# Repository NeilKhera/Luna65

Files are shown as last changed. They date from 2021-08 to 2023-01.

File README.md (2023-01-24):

## Luna65
Luna65 is my first PCB project - a 65% keyboard!

### Disclaimer
This is very much a WIP project which means there will be issues and incomplete features - especially on the software side. This is my first hardware project
and I do not claim to be an expert in the field. While physical versions of the PCB have been tested and are known to work, I do not promise that my implementation
is perfect. For example, the Atmega32u4 microprocessor used in this project does not have sufficient GPIO to enable a clean 5 row x 15 column matrix standard for 65%
keyboards. As such the keys are laid out in an unconventional (and definitely ugly) 6x12 matrix. I do not intend to improve or fix this.

TL;DR This project is provided as is. You are free to use it however you like but I have no intention to polish it into a complete ready-to-ship product. Functionality
may be added or removed at any moment and the project will be abandoned whenever I get too bored to carry on.
(Do, let me know if you actually get some boards made - that'd be sickkkkk!)

### License
Designed by Neil Khera.

Creative Commons Attribution/Share-Alike. See license.txt for additional details.

__

_fin._

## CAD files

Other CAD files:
resources/Draw1.DXF
resources/Luna65-Case-Bottom.DXF
resources/Luna65-Case-Top.DXF
resources/Luna65-Plate (Gasket).DXF
resources/Luna65-Case.DXF
resources/Luna65-Plate.DXF
resources/Draw1.SLDDRW

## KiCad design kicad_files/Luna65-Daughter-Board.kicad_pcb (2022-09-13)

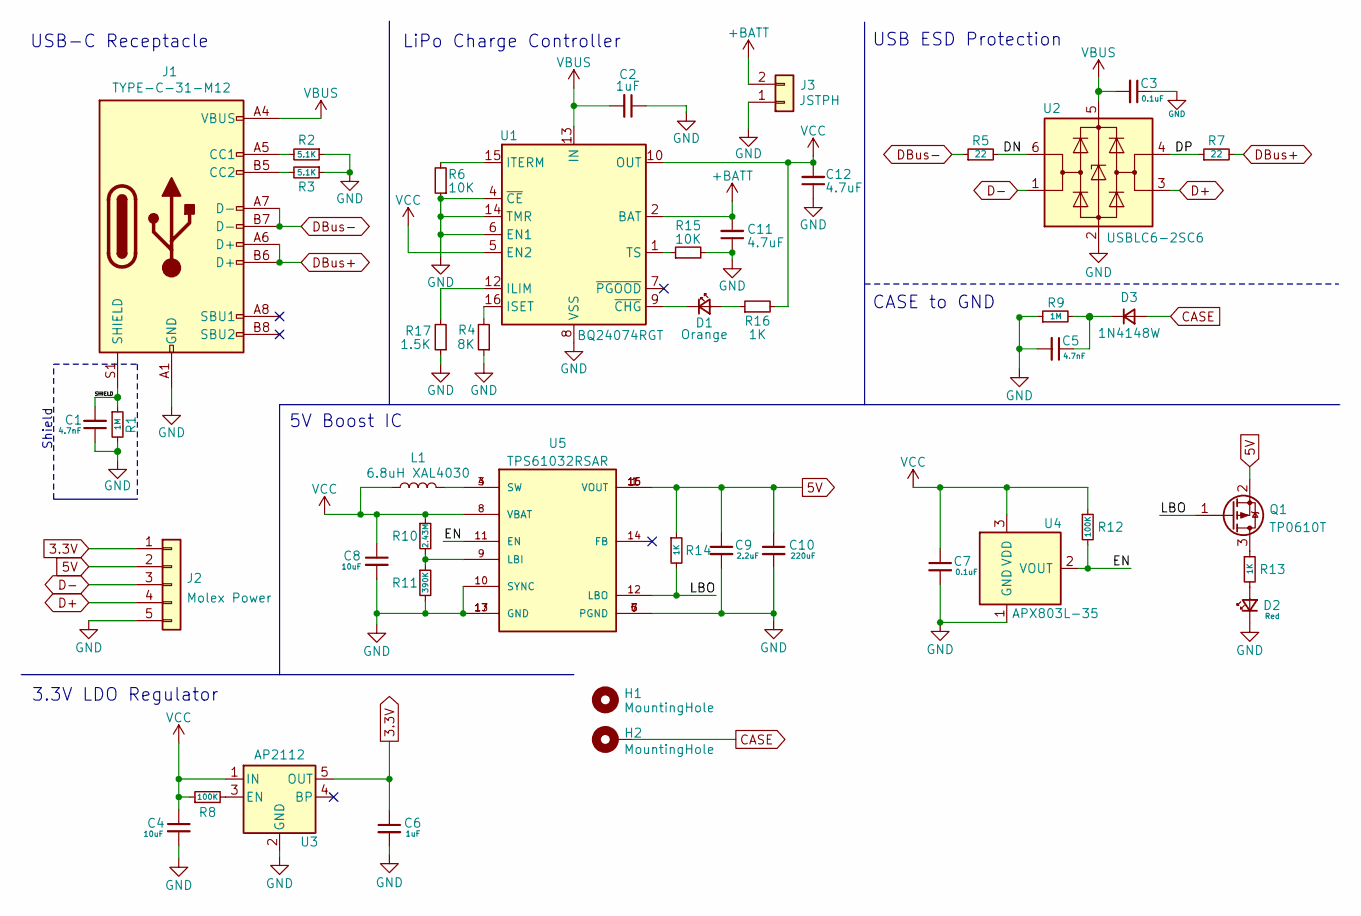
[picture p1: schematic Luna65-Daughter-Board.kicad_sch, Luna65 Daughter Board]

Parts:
C1, C5: 4.7nF; C_0603_1608Metric
C2, C6: 1uF; C_0603_1608Metric
C3, C7: 0.1uF; C_0603_1608Metric
C4, C8: 10uF; C_0603_1608Metric
C9: 2.2uF; C_0603_1608Metric
C10: 220uF; C_1206_3216Metric
C11, C12: 4.7uF; C_0603_1608Metric
D1: Orange; LED_0805_2012Metric
D2: Red; LED_0805_2012Metric
D3: 1N4148W; D_SOD-123
H1: MountingHole; MountingHole_2.2mm_M2
H2: MountingHole; MountingHole_2.2mm_M2_Pad
J1: TYPE-C-31-M12; USB_C_Receptacle_Hroparts_TYPE-C-31-M-12
J2: Molex Power; MOLEX_78171-0005
J3: JSTPH; JSTPH2
L1: 6.8uH XAL4030; XAL4030
Q1: TP0610T; SOT-23
R1, R9: 1M; R_0603_1608Metric
R2, R3: 5.1K; R_0603_1608Metric
R4: 8K; R_0603_1608Metric
R5, R7: 22; R_0603_1608Metric
R6, R15: 10K; R_0603_1608Metric
R8, R12: 100K; R_0603_1608Metric
R10: 2.43M; R_0603_1608Metric
R11: 390K; R_0603_1608Metric
R13, R14, R16: 1K; R_0603_1608Metric
R17: 1.5K; R_0603_1608Metric
U1: BQ24074RGT; VQFN-16-1EP_3x3mm_P0.5mm_EP1.6x1.6mm
U2: USBLC6-2SC6; SOT-23-6
U3: AP2112; SOT-23-5
U4: APX803L-35; SOT-23
U5: TPS61032RSAR; Texas_S-PVQFN-N16_EP2.7x2.7mm

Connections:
3.3V: C6.1, J2.1, U3.5 (OUT)
5V: C9.1, C10.1, J2.2, Q1.2 (S), R14.1, U5.1 (VOUT), U5.15 (VOUT), U5.16 (VOUT)
+BATT: C11.2, J3.2, U1.2 (BAT), U1.3 (BAT)
/DN: R5.2, U2.6 (I/O1)
/DP: R7.1, U2.4 (I/O2)
/EN: R12.2, U4.2 (VOUT), U5.11 (EN)
/LBO: Q1.1 (G), R14.2, U5.12 (LBO)
/SHIELD: C1.2, J1.S1 (SHIELD), R1.1
CASE: D3.2 (A), H2.1
D+: J2.4, U2.3 (I/O2)
D-: J2.3, U2.1 (I/O1)
DBus+: J1.A6 (D+), J1.B6 (D+), R7.2
DBus-: J1.A7 (D-), J1.B7 (D-), R5.1
GND: C1.1, C2.1, C3.1, C4.2, C5.2, C6.2, C7.2, C8.2, C9.2, C10.2, C11.1, C12.1, D2.1 (K), J1.A1 (GND), J1.B1 (GND), J2.5, J3.1, R1.2, R2.1, R3.1, R4.1, R6.1, R9.1, R11.2, R15.2, R17.1, U1.4 (~CE), U1.6 (EN1), U1.8 (VSS), U1.14 (TMR), U1.17 (VSS), U2.2 (GND), U3.2 (GND), U4.1 (GND), U5.5 (PGND), U5.6 (PGND), U5.7 (PGND), U5.10 (SYNC), U5.13 (GND), U5.17 (GND)
unnamed: C5.1, D3.1 (K), R9.2
unnamed: D1.1 (K), U1.9 (~CHG)
unnamed: D1.2 (A), R16.1
unnamed: D2.2 (A), R13.2
unnamed: J1.A5 (CC1), R2.2
unnamed: J1.B5 (CC2), R3.2
unnamed: L1.2, U5.3 (SW), U5.4 (SW)
unnamed: Q1.3 (D), R13.1
unnamed: R4.2, U1.16 (ISET)
unnamed: R6.2, U1.15 (ITERM)
unnamed: R8.2, U3.3 (EN)
unnamed: R10.2, R11.1, U5.9 (LBI)
unnamed: R15.1, U1.1 (TS)
unnamed: R17.2, U1.12 (ILIM)
VBUS: C2.2, C3.2, J1.A4 (VBUS), J1.B4 (VBUS), U1.13 (IN), U2.5 (VBUS)
VCC: C4.1, C7.1, C8.1, C12.2, L1.1, R8.1, R10.1, R12.1, R16.2, U1.5 (EN2), U1.10 (OUT), U1.11 (OUT), U3.1 (IN), U4.3 (VDD), U5.8 (VBAT)

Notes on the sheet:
3.3V LDO Regulator
5V Boost IC
CASE to GND
USB-C Receptacle
LiPo Charge Controller
Shield
USB ESD Protection

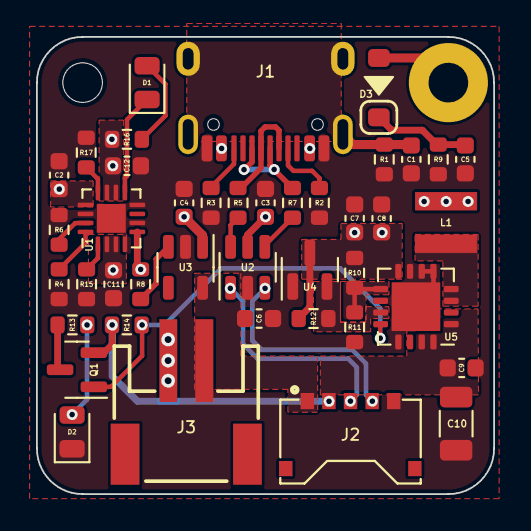
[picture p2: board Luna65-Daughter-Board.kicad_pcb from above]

Board: 2 copper layers, 25.4 x 25.4 mm, 44 parts (0 on the bottom side), 30 nets.

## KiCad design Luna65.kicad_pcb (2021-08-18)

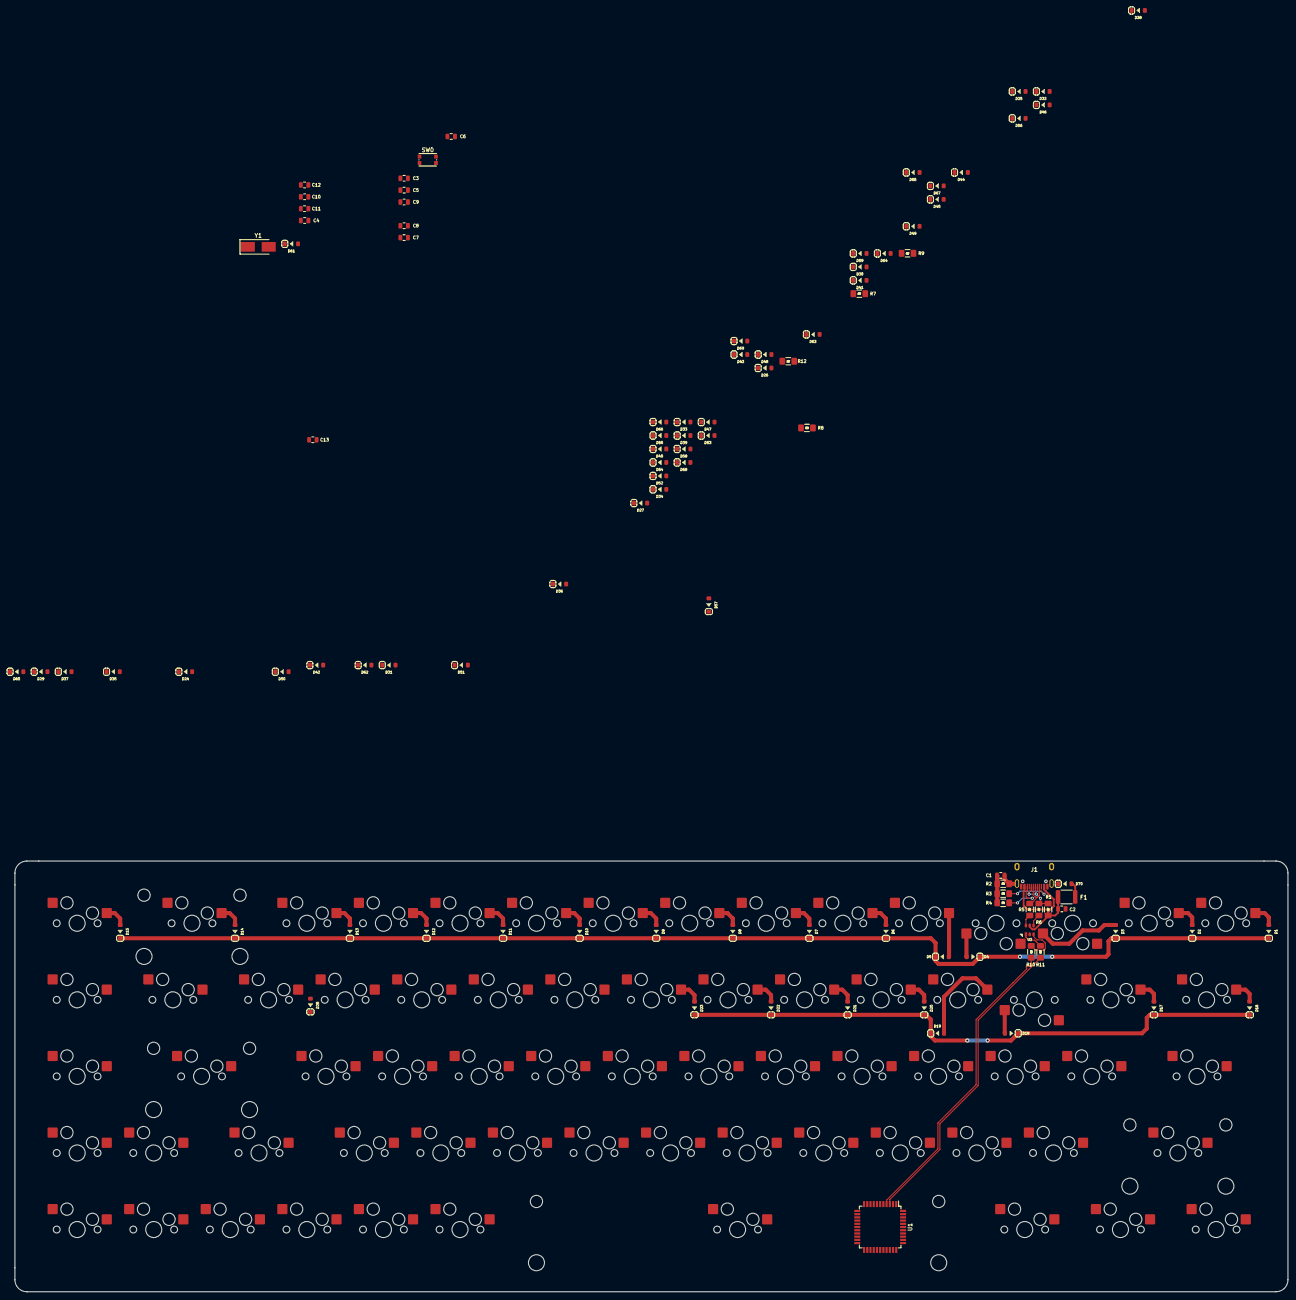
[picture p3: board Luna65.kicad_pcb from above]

Board: 2 copper layers, 316.7 x 107.2 mm, 169 parts (0 on the bottom side), 109 nets.

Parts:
C1, C13: 4.7nF; C_0805_2012Metric
C2: 100nF; C_0805_2012Metric
C3, C4, C8, C9: 0.1uF; C_0805_2012Metric
C5, C7, C12: 1uF; C_0805_2012Metric
C6: 10uF; C_0805_2012Metric
C10, C11: 22pF; C_0805_2012Metric
D1, D2, D3, D4, D5, D6, D7, D8, D9, D10, D11, D12, D13, D14, D15, D16, D17, D18, D19, D20, D21, D22, D23, D24, D25, D26, D27, D28, D29, D30, D31, D32, D33, D34, D35, D36, D37, D38, D39, D40, D41, D42, D43, D44, D45, D46, D47, D48, D49, D50, D51, D52, D53, D54, D55, D56, D57, D58, D59, D60, D61, D62, D63, D64, D65, D66, D67, D68: 1N4148W; D_SOD-123
D69: 1N4007; D_SOD-123
D70: RB060M-60TR; D_SOD-123
F1: Polyfuse_Small; Fuse_1812_4532
J1: TYPE-C-31-M12_13; TYPE-C-31-M-12
R1: 1.5K; R_SMD_1206
R2, R7: 1M; R_SMD_1206
R3, R4: 5.1k; R_SMD_1206
R5, R6, R10, R11: 22; R_SMD_1206
R8: 100; R_SMD_1206
R9: 10k; R_SMD_1206
R12: 1k; R_SMD_1206
SW0: SW_Push; SW_Push_1P1T_NO_CK_KMR2
SW1: Esc; MX100H
SW2: 1; MX100H
SW3: 2; MX100H
SW4: 3; MX100H
SW5: 4; MX100H
SW6: 5; MX100H
SW7: 6; MX100H
SW8: 7; MX100H
SW9: 8; MX100H
SW10: 9; MX100H
SW11: 0; MX100H
SW12: -; MX100H
SW13: =; MX100H
SW14: BSP_200; MX200H
SW15: Del; MX100H
SW16: Tab_150; MX150H
SW17: Q; MX100H
SW18: W; MX100H
SW19: E; MX100H
SW20: R; MX100H
SW21: T; MX100H
SW22: Y; MX100H
SW23: U; MX100H
SW24: I; MX100H
SW25: O; MX100H
SW26: P; MX100H
SW27: [; MX100H
SW28: ]; MX100H
SW29: \_150; MX150H
SW30: Home; MX100H
SW31: Caps_175; MX175H
SW32: A; MX100H
SW33: S; MX100H
SW34: D; MX100H
SW35: F; MX100H
SW36: G; MX100H
SW37: H; MX100H
SW38: J; MX100H
SW39: K; MX100H
SW40: L; MX100H
SW41: ;; MX100H
SW42: '; MX100H
SW43: Ent_225; MX225H
SW44: PgUp; MX100H
SW45: LShft_225; MX225H
SW46: Z; MX100H
SW47: X; MX100H
SW48: C; MX100H
SW49: V; MX100H
SW50: B; MX100H
SW51: N; MX100H
SW52: M; MX100H
SW53: ,; MX100H
SW54: .; MX100H
SW55: /; MX100H
SW56: RShft_175; MX175H
SW57: Up; MX100H
SW58: End; MX100H
SW59: LCtrl_125; MX125H
SW60: Win_125; MX125H
SW61: LAlt_125; MX125H
SW62: Space_625; MX625H
SW63: RAlt; MX100H
SW64: Fn; MX100H
SW65: RCtrl; MX100H
SW66: Left; MX100H
SW67: Down; MX100H
SW68: Right; MX100H
U1: ATmega32U4-AU; TQFP-44_10x10mm_P0.8mm
U2: USBLC6-2SC6; SOT-23-6
Y1: 16MHz; Crystal_SMD_5032-2Pin_5.0x3.2mm_HandSoldering

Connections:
5V: C3.1, C4.1, C5.1, C6.1, C7.1, C8.1, D70.2 (A), F1.2, R9.1, U1.2 (UVCC), U1.7 (VBUS), U1.14 (VCC), U1.24 (AVCC), U1.34 (VCC), U1.42 (AREF), U1.44 (AVCC)
/DN: R5.2, U2.6 (I/O1)
/DN2: R11.1, U1.3 (D-)
/DP: R6.1, U2.4 (I/O2)
/DP2: R10.1, U1.4 (D+)
/SHIELD: C1.2, J1.S (SHIELD), R2.1
Col1: SW1.1 (Col), SW16.1 (Col), SW31.1 (Col), SW45.1 (Col), SW59.1 (Col), U1.36 (PF7)
Col2: SW2.1 (Col), SW17.1 (Col), SW32.1 (Col), SW46.1 (Col), SW60.1 (Col), U1.37 (PF6)
Col3: SW3.1 (Col), SW18.1 (Col), SW33.1 (Col), SW47.1 (Col), SW61.1 (Col), U1.38 (PF5)
Col4: SW4.1 (Col), SW19.1 (Col), SW34.1 (Col), SW48.1 (Col), U1.39 (PF4)
Col5: SW5.1 (Col), SW20.1 (Col), SW35.1 (Col), SW49.1 (Col), U1.18 (PD0)
Col6: SW6.1 (Col), SW21.1 (Col), SW36.1 (Col), SW50.1 (Col), SW62.1 (Col), U1.19 (PD1)
Col7: SW7.1 (Col), SW22.1 (Col), SW37.1 (Col), SW51.1 (Col), U1.20 (PD2)
Col8: SW8.1 (Col), SW23.1 (Col), SW38.1 (Col), SW52.1 (Col), U1.21 (PD3)
Col9: SW9.1 (Col), SW24.1 (Col), SW39.1 (Col), SW53.1 (Col), U1.22 (PD5)
Col10: SW10.1 (Col), SW25.1 (Col), SW40.1 (Col), SW54.1 (Col), SW63.1 (Col), U1.27 (PD7)
Col11: SW11.1 (Col), SW26.1 (Col), SW41.1 (Col), SW55.1 (Col), SW64.1 (Col), U1.28 (PB4)
Col12: SW12.1 (Col), SW27.1 (Col), SW42.1 (Col), SW56.1 (Col), SW65.1 (Col), U1.29 (PB5)
Col13: SW13.1 (Col), SW28.1 (Col), SW43.1 (Col), SW66.1 (Col), U1.30 (PB6)
Col14: SW14.1 (Col), SW29.1 (Col), SW57.1 (Col), SW67.1 (Col), U1.31 (PC6)
Col15: SW15.1 (Col), SW30.1 (Col), SW44.1 (Col), SW58.1 (Col), SW68.1 (Col)
D+: R10.2, U2.3 (I/O2)
D-: R11.2, U2.1 (I/O1)
DBus+: J1.A6 (D+), J1.B6 (D+), R1.1, R6.2
DBus-: J1.A7 (D-), J1.B7 (D-), R5.1
GND: C1.1, C2.1, C3.2, C4.2, C5.2, C6.2, C7.2, C8.2, C9.2, C10.2, C11.2, C12.2, C13.2, D70.1 (K), J1.A1 (GND), J1.B1 (GND), R2.2, R3.1, R4.1, R7.1, R8.2, R12.1, U1.5 (UGND), U1.15 (GND), U1.23 (GND), U1.35 (GND), U1.43 (GND), U2.2 (GND)
unnamed: C9.1, R9.2, SW0.2, U1.13 (~RESET)
unnamed: C10.1, U1.17 (XTAL1), Y1.2
unnamed: C11.1, U1.16 (XTAL2), Y1.1
unnamed: C12.1, U1.6 (UCAP)
unnamed: C13.1, D69.1 (K), R7.2
unnamed: D1.2 (A), SW1.2 (Row)
unnamed: D2.2 (A), SW2.2 (Row)
unnamed: D3.2 (A), SW3.2 (Row)
unnamed: D4.2 (A), SW4.2 (Row)
unnamed: D5.2 (A), SW5.2 (Row)
unnamed: D6.2 (A), SW6.2 (Row)
unnamed: D7.2 (A), SW7.2 (Row)
unnamed: D8.2 (A), SW8.2 (Row)
unnamed: D9.2 (A), SW9.2 (Row)
unnamed: D10.2 (A), SW10.2 (Row)
unnamed: D11.2 (A), SW11.2 (Row)
unnamed: D12.2 (A), SW12.2 (Row)
unnamed: D13.2 (A), SW13.2 (Row)
unnamed: D14.2 (A), SW14.2 (Row)
unnamed: D15.2 (A), SW15.2 (Row)
unnamed: D16.2 (A), SW16.2 (Row)
unnamed: D17.2 (A), SW17.2 (Row)
unnamed: D18.2 (A), SW18.2 (Row)
unnamed: D19.2 (A), SW19.2 (Row)
unnamed: D20.2 (A), SW20.2 (Row)
unnamed: D21.2 (A), SW21.2 (Row)
unnamed: D22.2 (A), SW22.2 (Row)
unnamed: D23.2 (A), SW23.2 (Row)
unnamed: D24.2 (A), SW24.2 (Row)
unnamed: D25.2 (A), SW25.2 (Row)
unnamed: D26.2 (A), SW26.2 (Row)
unnamed: D27.2 (A), SW27.2 (Row)
unnamed: D28.2 (A), SW28.2 (Row)
unnamed: D29.2 (A), SW29.2 (Row)
unnamed: D30.2 (A), SW30.2 (Row)
unnamed: D31.2 (A), SW31.2 (Row)
unnamed: D32.2 (A), SW32.2 (Row)
unnamed: D33.2 (A), SW33.2 (Row)
unnamed: D34.2 (A), SW34.2 (Row)
unnamed: D35.2 (A), SW35.2 (Row)
unnamed: D36.2 (A), SW36.2 (Row)
unnamed: D37.2 (A), SW37.2 (Row)
unnamed: D38.2 (A), SW38.2 (Row)
unnamed: D39.2 (A), SW39.2 (Row)
unnamed: D40.2 (A), SW40.2 (Row)
unnamed: D41.2 (A), SW41.2 (Row)
unnamed: D42.2 (A), SW42.2 (Row)
unnamed: D43.2 (A), SW43.2 (Row)
unnamed: D44.2 (A), SW44.2 (Row)
unnamed: D45.2 (A), SW45.2 (Row)
unnamed: D46.2 (A), SW46.2 (Row)
unnamed: D47.2 (A), SW47.2 (Row)
unnamed: D48.2 (A), SW48.2 (Row)
unnamed: D49.2 (A), SW49.2 (Row)
unnamed: D50.2 (A), SW50.2 (Row)
unnamed: D51.2 (A), SW51.2 (Row)
unnamed: D52.2 (A), SW52.2 (Row)
unnamed: D53.2 (A), SW53.2 (Row)
unnamed: D54.2 (A), SW54.2 (Row)
unnamed: D55.2 (A), SW55.2 (Row)
unnamed: D56.2 (A), SW56.2 (Row)
unnamed: D57.2 (A), SW57.2 (Row)
unnamed: D58.2 (A), SW58.2 (Row)
unnamed: D59.2 (A), SW59.2 (Row)
unnamed: D60.2 (A), SW60.2 (Row)
unnamed: D61.2 (A), SW61.2 (Row)
unnamed: D62.2 (A), SW62.2 (Row)
unnamed: D63.2 (A), SW63.2 (Row)
unnamed: D64.2 (A), SW64.2 (Row)
unnamed: D65.2 (A), SW65.2 (Row)
unnamed: D66.2 (A), SW66.2 (Row)
unnamed: D67.2 (A), SW67.2 (Row)
unnamed: D68.2 (A), SW68.2 (Row)
unnamed: J1.A5 (CC1), R3.2
unnamed: J1.B5 (CC2), R4.2
unnamed: R8.1, SW0.1
unnamed: R12.2, U1.33 (~HWB~/PE2)
Row1: D1.1 (K), D2.1 (K), D3.1 (K), D4.1 (K), D5.1 (K), D6.1 (K), D7.1 (K), D8.1 (K), D9.1 (K), D10.1 (K), D11.1 (K), D12.1 (K), D13.1 (K), D14.1 (K), D15.1 (K), U1.10 (PB2)
Row2: D16.1 (K), D17.1 (K), D18.1 (K), D19.1 (K), D20.1 (K), D21.1 (K), D22.1 (K), D23.1 (K), D24.1 (K), D25.1 (K), D26.1 (K), D27.1 (K), D28.1 (K), D29.1 (K), D30.1 (K), U1.11 (PB3)
Row3: D31.1 (K), D32.1 (K), D33.1 (K), D34.1 (K), D35.1 (K), D36.1 (K), D37.1 (K), D38.1 (K), D39.1 (K), D40.1 (K), D41.1 (K), D42.1 (K), D43.1 (K), D44.1 (K), U1.40 (PF1)
Row4: D45.1 (K), D46.1 (K), D47.1 (K), D48.1 (K), D49.1 (K), D50.1 (K), D51.1 (K), D52.1 (K), D53.1 (K), D54.1 (K), D55.1 (K), D56.1 (K), D57.1 (K), D58.1 (K), U1.32 (PC7)
Row5: D59.1 (K), D60.1 (K), D61.1 (K), D62.1 (K), D63.1 (K), D64.1 (K), D65.1 (K), D66.1 (K), D67.1 (K), D68.1 (K)
VBUS: C2.2, F1.1, J1.A4 (VBUS), J1.B4 (VBUS), R1.2, U2.5 (VBUS)

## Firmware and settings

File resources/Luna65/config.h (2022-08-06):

/*
Copyright 2021 Neil Khera

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
You should have received a copy of the GNU General Public License
along with this program.  If not, see <http://www.gnu.org/licenses/>.
*/

#pragma once

#include "config_common.h"

#define AdafruitBleCSPin B0

/* USB Device descriptor parameter */
#define VENDOR_ID       0x1111
#define PRODUCT_ID      0x1024
#define DEVICE_VER      0x0001
#define MANUFACTURER    NeilKhera
#define PRODUCT         Luna65
#define DESCRIPTION     Luna65 with BT

/* key matrix size */
#define MATRIX_ROWS 6
#define MATRIX_COLS 12

/*
 * Keyboard Matrix Assignments
 *
 * Change this to how you wired your keyboard
 * COLS: AVR pins used for columns, left to right
tyre
 * DIODE_DIRECTION: COL2ROW = COL = Anode (+), ROW = Cathode (-, marked on diode)
 *                  ROW2COL = ROW = Anode (+), COL = Cathode (-, marked on diode)
 *
*/
#define MATRIX_COL_PINS { D4, D6, D7, B4, B5, B6, C6, C7, F4, F5, F6, F7 }
#define MATRIX_ROW_PINS { D1, D2, F1, F0, D3, D5 }
#define UNUSED_PINS

/* COL2ROW, ROW2COL, or CUSTOM_MATRIX */
#define DIODE_DIRECTION COL2ROW

#define RGB_DI_PIN B7
// The number of LEDs connected
#define DRIVER_LED_TOTAL 6
#define RGB_MATRIX_MAXIMUM_BRIGHTNESS 80

#define BACKLIGHT_PIN D0
#define BACKLIGHT_DRIVER = pwm
#define BACKLIGHT_LEVELS 5
#define BACKLIGHT_ON_STATE 0

/* Debounce reduces chatter (unintended double-presses) - set 0 if debouncing is not needed */
#define DEBOUNCE 5

/* Mechanical locking support. Use KC_LCAP, KC_LNUM or KC_LSCR instead in keymap */
#define LOCKING_SUPPORT_ENABLE

/* Locking resynchronize hack */
#define LOCKING_RESYNC_ENABLE

#define TAPPING_TERM 100

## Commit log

2021-08-05 Update Paths
    [Luna50.kicad_pcb]
2021-08-18 Luna65 Changes
    [Luna50.kicad_pcb, Luna50.kicad_sch, Luna65.kicad_pcb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]
2021-08-19 Completed routing
    [Luna65.kicad_sch]
2021-09-09 CAD files
    [kb-Body.stl, kb.FCStd]
2021-09-12 Schematic fixes. Prep for LEDs
    [Luna65.kicad_sch]
2021-09-12 Folder Cleanup
    [kb-Body.stl, kb.FCStd]
2021-09-29 V3 Changes
    [Luna65.kicad_sch, kb-Body.stl, kb.FCStd]
2021-10-05 Done with v3
    [Luna65.kicad_sch]
2021-11-02 Added DXFs
    [Luna65-Case.DXF, Luna65-Plate.DXF]
2021-11-07 new changes for v4
    [Luna65.kicad_sch]
2021-11-09 Finished V4 routing
    [Luna65.kicad_sch]
2021-11-19 Firmware V4
    [Luna65-Plate.DXF]
2021-11-27 Rev 5
    [Luna65.kicad_sch]
2021-12-08 Fixed Broken Bluetooth
    [Luna65.kicad_sch]
2021-12-08 Update Schematic Ver
    [Luna65.kicad_sch]
2021-12-12 Updated Case DXF
    [Luna65-Case.DXF]
2022-02-12 Refactoring 1
    [Luna65-Case.DXF, Luna65-Plate.DXF, Luna65.kicad_sch]
2022-02-16 Rev 6 initial changes
    [Luna65-Daughter-Board.kicad_pcb, Luna65-Daughter-Board.kicad_sch, Luna65.kicad_sch]
2022-02-17 Rev 6 pre-production updates
    [Luna65-Daughter-Board.kicad_pcb]
2022-02-26 DB Rev B
    [Luna65-Daughter-Board.kicad_pcb, Luna65-Daughter-Board.kicad_sch]
2022-03-04 DB Rev C
    [Luna65-Daughter-Board.kicad_pcb, Luna65-Daughter-Board.kicad_sch, Luna65.kicad_sch]
2022-03-09 Updated QMK firmware to support RGB. Cleaned up routing somewhat
    [Luna65-Daughter-Board.kicad_pcb, Luna65.kicad_sch]
2022-03-09 Added 0 Ohm resistor to isolate BT and uC 3.3V
    [Luna65-Daughter-Board.kicad_pcb, Luna65-Daughter-Board.kicad_sch, Luna65.kicad_sch]
2022-03-09 Finished Daughterboard 3D model
    [Luna65-Daughter-Board.kicad_pcb]
2022-03-12 Limit RGB max brightness
    [Luna65-Daughter-Board.kicad_pcb, Luna65-Daughter-Board.kicad_sch]
2022-03-19 Added Gasket Mount Plate DXF
    [Luna65-Plate (Gasket).DXF]
2022-04-01 DB Rev 4 Changes
    [Luna65-Daughter-Board.kicad_pcb, Luna65-Daughter-Board.kicad_sch]
2022-04-07 Added Gasket mount case design
    [Luna65-Case-Bottom.DXF, Luna65-Case-Top.DXF]
2022-06-13 V7 Changes
    [Luna65-Daughter-Board.kicad_pcb, Luna65.kicad_sch]
2022-09-13 DB Rev 8
    [Luna65-Daughter-Board.kicad_pcb, Luna65-Daughter-Board.kicad_sch]

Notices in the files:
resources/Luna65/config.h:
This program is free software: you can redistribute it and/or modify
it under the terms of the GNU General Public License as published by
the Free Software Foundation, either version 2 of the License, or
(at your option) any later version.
